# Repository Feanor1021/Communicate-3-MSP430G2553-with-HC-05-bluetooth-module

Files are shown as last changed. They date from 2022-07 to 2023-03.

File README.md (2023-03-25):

# Communicate-3-MSP430G2553-with-HC-05-bluetooth-module

This is a project for communicating between three MSP430G2553 microcontrollers using the HC-05 Bluetooth module. 

## Project Overview

The project consists of three MSP430G2553 microcontrollers connected to HC-05 Bluetooth modules. One microcontroller is designated as the master, and the other two are slaves. The master microcontroller sends commands to the slaves, and the slaves respond with their status. The status of each slave is indicated by an LED on the corresponding microcontroller.

## Usage

### Hardware Setup

The following hardware is required for this project:

- Three MSP430G2553 microcontrollers
- Three HC-05 Bluetooth modules
- Look to altium file for other components (LED, Res, Cap, etc)

The hardware should be set up as shown in the altium file

### Software Setup

To set up the software for this project, you will need to install IAR Studio (Or CCS) and the MSP430G2553 driver. 
Once IAR Studio is installed, open the project in IAR Studio and build the code for each microcontroller. 
You need to change the code for your hc-05 devices. Master device should know the slave device's MAC adresses.

### Usage

Once the hardware and software are set up, turn on the microcontrollers and they will pair them with the master HC-05 automaticaly. 
The slave microcontrollers will respond with their status. If the LED is on, the status will be `on`. If the LED is off, the status will be `off`. Other leds will
be on or off respect to the sensors status.

    FOR DETAILED INFORMATION READ THE RAPOR.

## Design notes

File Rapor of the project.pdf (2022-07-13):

MSP430 9TH PROJECT REFERENCE DOCUMENT

pg. 1

### KOCAELİ UNIVERSITY ENGINEERING FACULTY

# DATA TRANSFER

# BETWEEN 3

# MSP430G2553 VİA

# BLUETOOTH MODULE

HC-05

FURKAN YARDIMCI
210207089
2021-2022

### DEPARTMENT: Electronic and Communacition Engineering

TEACHER: Dr.Öğr.Üyesi AYHAN KÜÇÜKMANİSA (https://avesis.kocaeli.edu.tr/ayhan.kucukmanisa/)

### KOCAELİ, 2021

TABLE OF CONTENTS

ABSTRACT |
BACKGROUND |
•MSP430G2553 |
•HC-05 And Main Logic Of The Embeded System |
What Is AT Commands |
AT commands that we use in our project |
Main Logic |
- FLAME SENSOR |
•MQ-4 GAS SENSOR |
SYSTEM DESİGN |
•SCHEMATİC AND PCB |
•CODES |
CODES OF SLAVES |
CODE OF MASTER |
IMAGES OF THE SYSTEM IN OPERATING MODE |
REFERENCES |

### 1.ABSTRACT:

An embedded system application that communicates 3 msp430g2553 via bluetooth modules. Using the Bluetooth module (hc-05), 2 slave and 1 master configurations are set between the msps. As a result of analog data coming from the slaves, which came from Fire sensor and MQ-4 gas sensor, the led indicators connected to the master light up.

### 2.BACKGROUND:

### 2.1 MSP430G2553:

Texas Instruments MSP430G2553 is part of the MSP430 family of ultra-low-power microcontrollers featuring different sets of peripherals. The MSP430G2553 mixed signal microcontroller features a 16-bit Semi RISC CPU, 16-bit registers, 16KB non-volatile memory, 512 bytes RAM. The G2x53 series is popular due to the low price and various package sizes. We have use 3 msp430g2553 in our project, 2 of them act as slaves and one is master.

### 2.2 HC-05 And Main Logic Of The Embeded System:

HC-05 Bluetooth Module is an easy to use Bluetooth SPP (Serial Port Protocol) module, designed for transparent wireless serial connection setup. Its communication is via serial communication which makes an easy way to interface with controller or PC. HC-05 Bluetooth module provides switching mode between master and slave mode which means it able to use neither receiving nor transmitting data. Master, slave modes and lots of modes are, arrenged with AT command of the hc-05, wich is so important for our project

a)What Is AT Commands ?

By default, the HC-05 is configured in data mode. In this mode, the module acts like a serial bridge. If you want to set an HC-05 as a master you have to put it into AT command mode. To put into AT command mode the KEY pin must be set (high). The HC-05 is now in command mode if the red LED flashes once every two seconds.

b)AT commands that we use in our project:

Set/Inquire module role:
AT+ROLE=PARAM1 → Role introduction: Slave: Passive connection; Slave-Loop: Passive connection, receive the remote Bluetooth master device data and send it back to the master device; Master: Inquire the near SPP Bluetooth slave device, build connection with it positively, and build up the transparent data transmission between master and slave device. Default: 0

Param1: module role: 0 -> Slave
1 -> Master
2 -> Slave-Loop

Set/Inquire connection mode:
AT+CMODE=Param1→ Param1: Connection mode: 0 -> Connect the module to the specified Bluetooth address. (Bluetooth address can be specified by the binding command)
1 -> Connect the module to any address (The specifying address has no effect for this mode.) 2 -> Slave-Loop
Default connection mode: 0

Set/Inquire - bind Bluetooth address:
AT+BIND=Param1 → Param1: Bluetooth address: needed to be bind

Connect Device :
AT+LINK=Param1 → Param1: Bluetooth address of remote device

AT commands of master hc-05 is:

AT+ROLE=1 AT+CMODE=0

AT commands of slaves is:

AT+ROLE=0 AT+CMODE=1;

c)Main Logic:

In our project we have 2 slaves and 1 master but hc-05 is support just one slave connection to the master at a time. As a solution to this, the master was cycled between continuous in AT mode and data mode, and we achived this with switching the reset pin(11th pin) of Hc-05 with BC238 switch circuit. First master hc-05 is goes into the at mode, then the address of the 1st slave is bind to master, then it has reset and goes into data mode, and it is communicate with slave 1. With this loopish approach, we have able to control 2 slaves with a single master.

### 2.3 Flame Sensor:

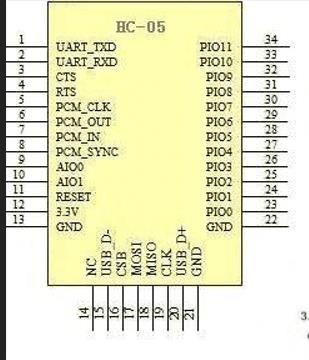
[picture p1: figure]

The fire detector sensor card is a sensor card used to detect fire with a wavelength between 760 nm -1100 nm. It has an IR receiver on it. It can be used as a fire detection sensor in fire extinguishing robots. Sensitivity can be adjusted with the trimpot on it and both analog and digital output can be output.

### 2.4 MQ-4 Gas Sensor:

The MQ-4 methane gas sensor detects the presence of methane (CNG) natural gas in a range of concentrations suitable for gas leak detection between 300ppm and 10000ppm. Like other MQ sensors, this sensor also gives an analog voltage output according to the density of the gas. Being able to detect between 10.000ppm and 300ppm is suitable for gas leakage.

### 3. System Design

### 3.1 Schematic and PCB:

This system’s schematic was designed using Altium Designer 17.0 and can be seen in the Figure below...

a)MASTER Circuit:

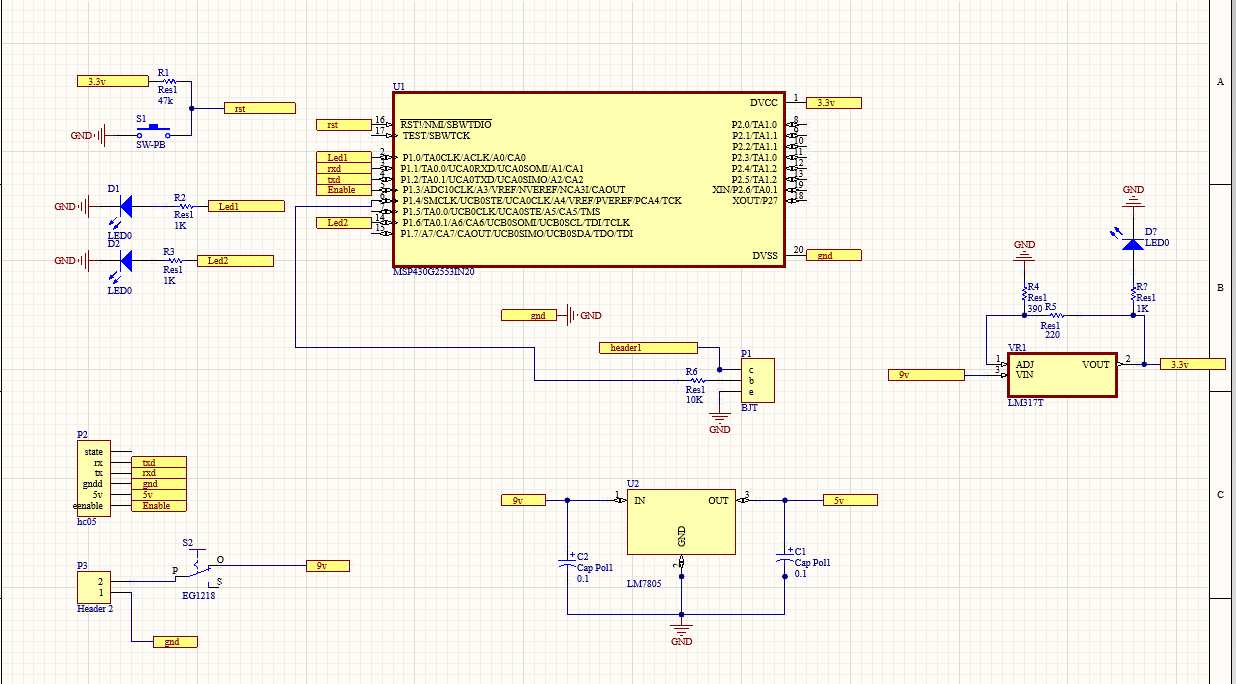
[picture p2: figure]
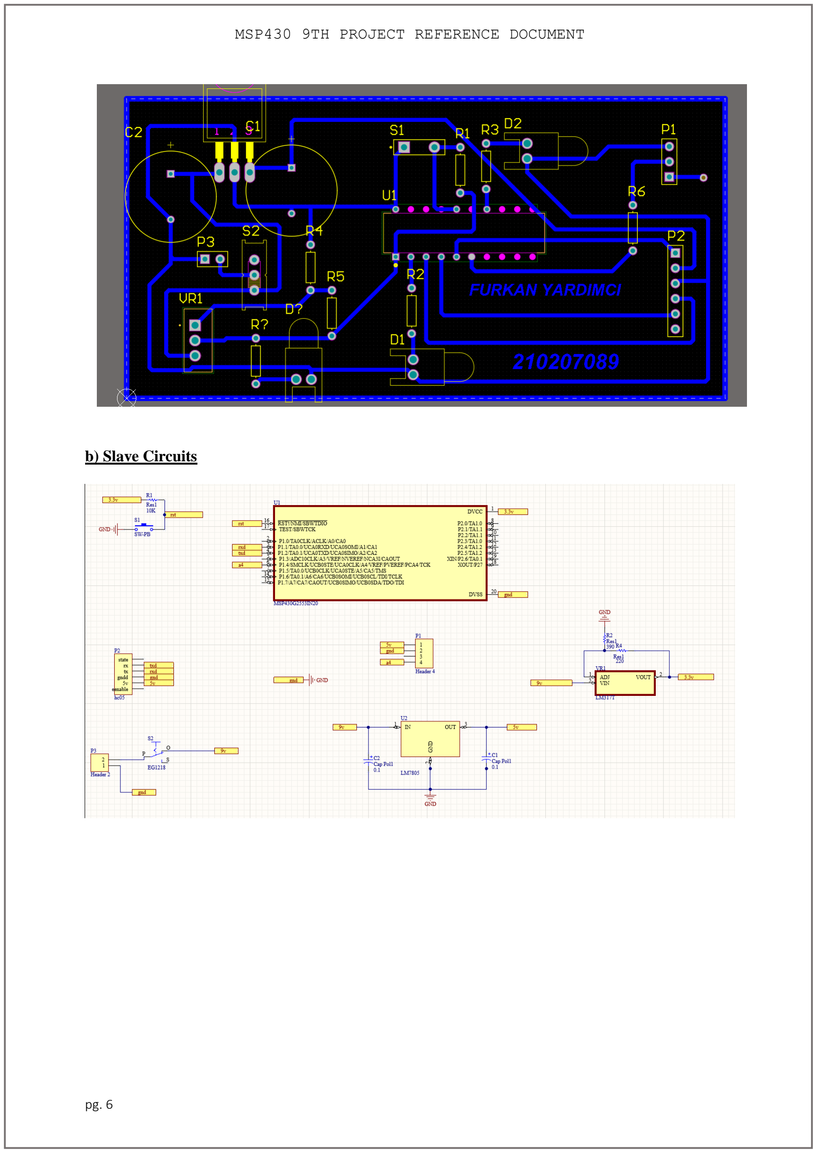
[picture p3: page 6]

b) Slave Circuits

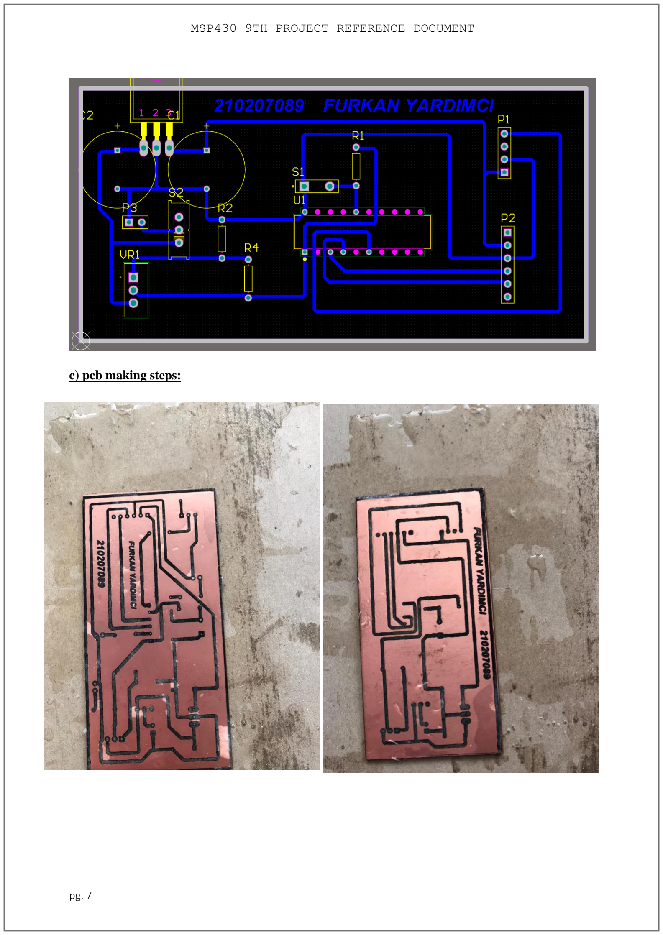
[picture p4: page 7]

c) pcb making steps:

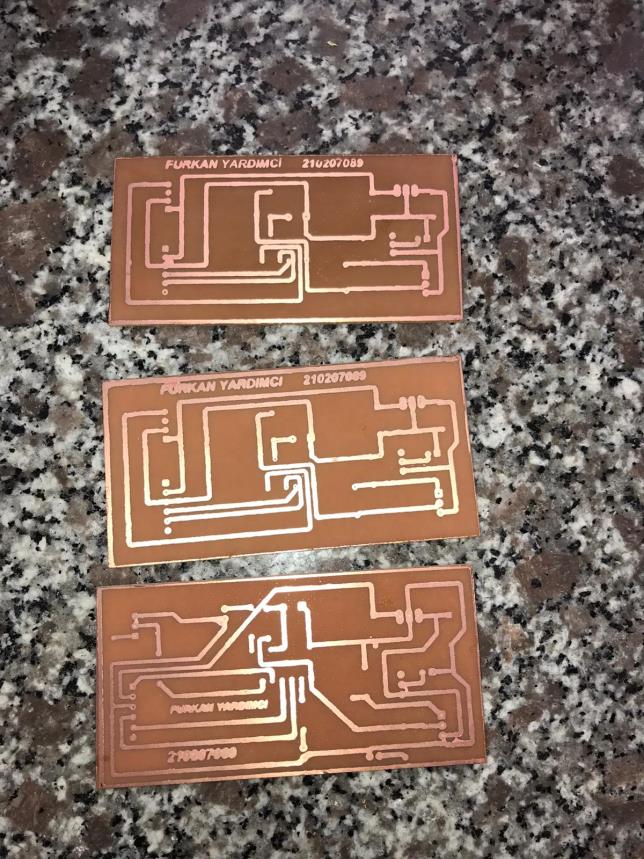
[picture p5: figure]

### 3.2 Codes:

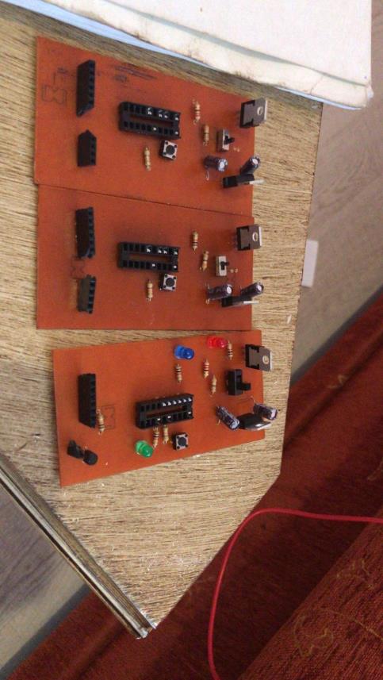
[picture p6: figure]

This project code was written in c language and separate codes were written for master and slaves.

a.1) CODES OF SLAVES: slave codes are almost exactly the same so I'm just putting one of them in the report

ADC Register Initializations

Register | Bit | Description
ADC10CTL0 | REFON | Reference generator: ON
ADC10CTL0 | SREF_1 | Select reference voltage as 1.5v
ADC10CTL0 | ADC10ON | ADC10 Enable: ON
ADC10CTL0 | ADC10IE | ADC10 Interrupt: ENABLED
ADC10CTL0 | ADC10SHT_3 | Sample and holde time: 64xAdc10clk
ADC10CTL0 | ENC | Enable conversion
ADC10CTL0 | ADC10SC | Start Conversion
ADC10CTL1 | INCH_4 | Input channel A4 (P1.4)
ADC10CTL1 | ADC10SSEL_0 | ADC10OSC selected as a clk source

ADC10CTL1 | ADC10DIV_3 | ADC10OSC clk divided by 2
ADC10AE | BIT4 | Analog input enable bit is set for Port 1.4

UART Register Initializations

Register | Bit | Description
P1SEL | BIT1 + BIT2 | P1.1 = RXD, P1.2=TXD
P1SEL2 | BIT1 + BIT2 | P1.1 = RXD, P1.2=TXD
UCA0CTL1 | UCSSEL_2 | Set UART use SMCLK
UCA0BR0 | 104 | 1MHz 9600 baud
UCA0BR1 | 0 | 1MHz 9600 baud
UCA0MCTL | UCBRS_1 | Modulation UCBRSx = 1
IE2 | UCA0RXIE | Rx interrupts are enabled
UCA0CTL1 | ~UCSWRST | Resets are disabled

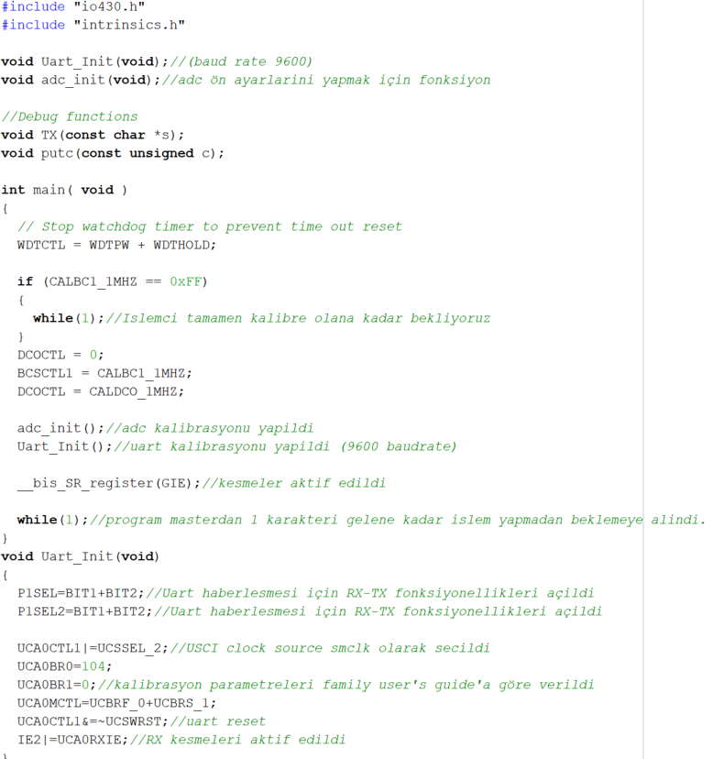
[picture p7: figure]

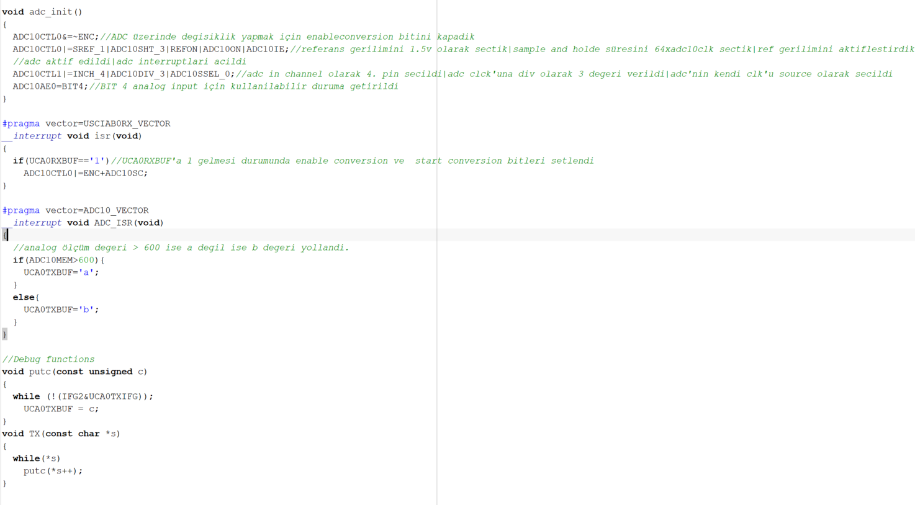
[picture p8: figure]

a.2) Functions:

Function | Description
void TX(const char *s) | Send a string via UART
void putc(const unsigned c) | Send a character via UART
void Uart_Init(void); | Initilazation of Uart communication
void adc_init(void); | Initilazation of ADC10
b) Code Of Master:

UART Register Initializations for 9600 baud rate. This baud rate used for BT to BT communication.

Register | Bit | Description
P1SEL | BIT1 + BIT2 | P1.1 = RXD, P1.2=TXD
P1SEL2 | BIT1 + BIT2 | P1.1 = RXD, P1.2=TXD
UCA0CTL1 | UCSSEL_2 | Set UART use SMCLK
UCA0BR0 | 104 | 1MHz 9600 baud
UCA0BR1 | 0 | 1MHz 9600 baud
UCA0MCTL | UCBRS_1 | Modulation UCBRSx = 1
IE2 | UCA0RXIE | Rx interrupts are enabled
UCA0CTL1 | ~UCSWRST | Resets are disabled

UART Register Initializations for 38400 baud rate. This baud rate used for sending AT command to the module

Register | Bit | Description
P1SEL | BIT1 + BIT2 | P1.1 = RXD, P1.2=TXD
P1SEL2 | BIT1 + BIT2 | P1.1 = RXD, P1.2=TXD
UCA0CTL1 | UCSSEL_2 | Set UART use SMCLK
UCA0BR0 | 26 | 1MHz 9600 baud
UCA0BR1 | 0 | 1MHz 9600 baud
UCA0MCTL | UCBRS_0 | Modulation UCBRSx = 0
IE2 | UCA0RXIE | Rx interrupts are enabled
UCA0CTL1 | ~UCSWRST | Resets are disabled

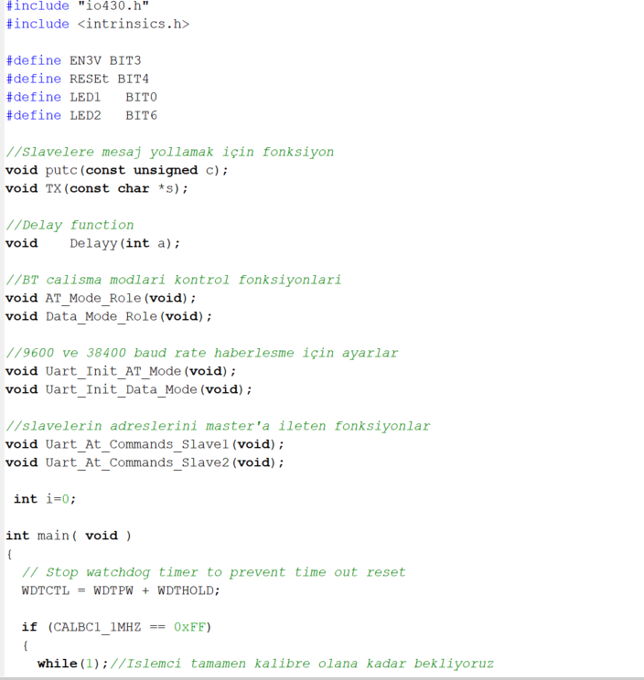
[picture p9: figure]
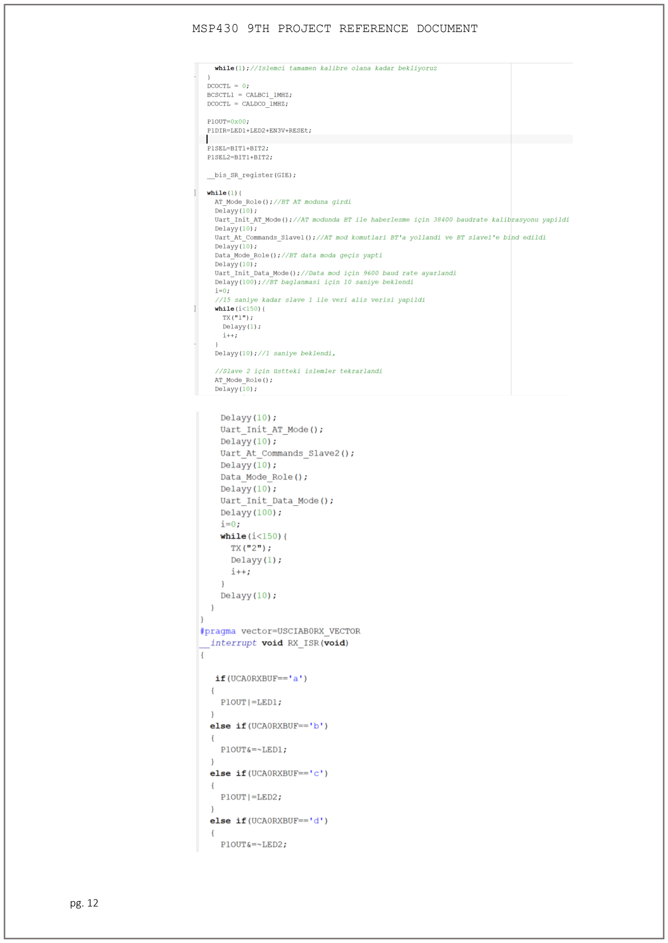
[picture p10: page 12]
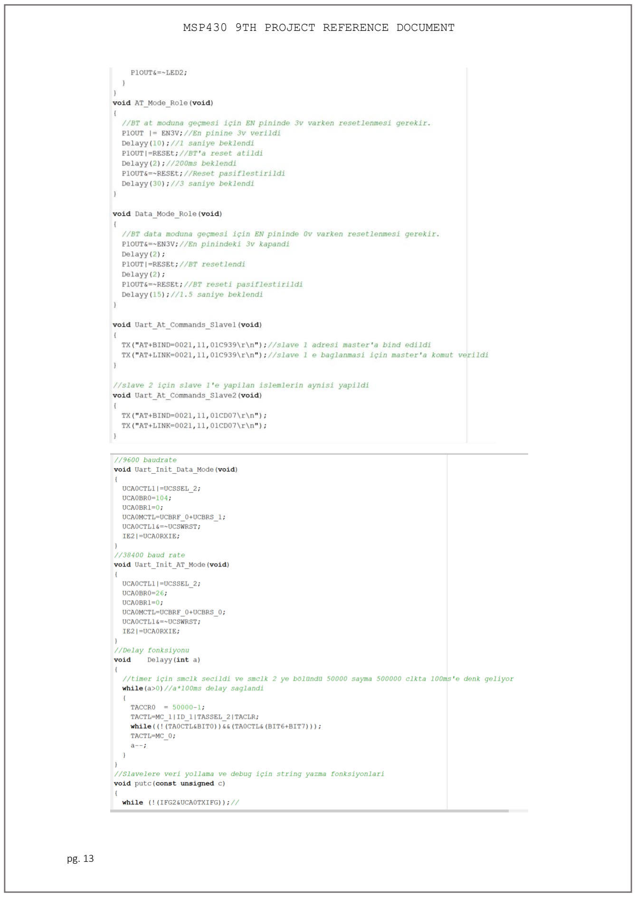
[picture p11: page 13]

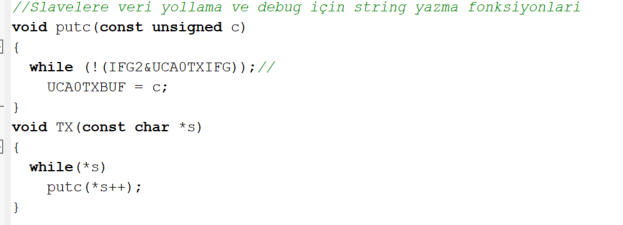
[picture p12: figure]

b.2) Functions:

Function | Description
void TX(const char *s) | Send a string via UART
void putc(const unsigned c) | Send a character via UART
void Uart_Init(void); | Initilazation of Uart communication
void adc_init(void); | Initilazation of ADC10
void Delayy(int a); | A function that produces a delay of a*100ms
void AT_Mode_Role(void); | Function that makes the necessary bias setting for Bluetooth to switch to at mode
void Data_Mode_Role(void); | Function that makes the necessary bias setting for Bluetooth to switch to data mode
void Uart_Init_AT_Mode(void); | Function that initialize uart setting for at mode of the Bluetooth module.(38400 baud rate)
void Uart_Init_Data_Mode(void); | Function that initialize uart setting for data mode of the Bluetooth module.(9600 baud rate)
Void Uart_At_Commands_Slave1(void); | Function that bind and connect master to slave 1
void Uart_At_Commands_Slave2(void); | Function that bind and connect master to slave 2

### 4. Images Of The System In Operation:

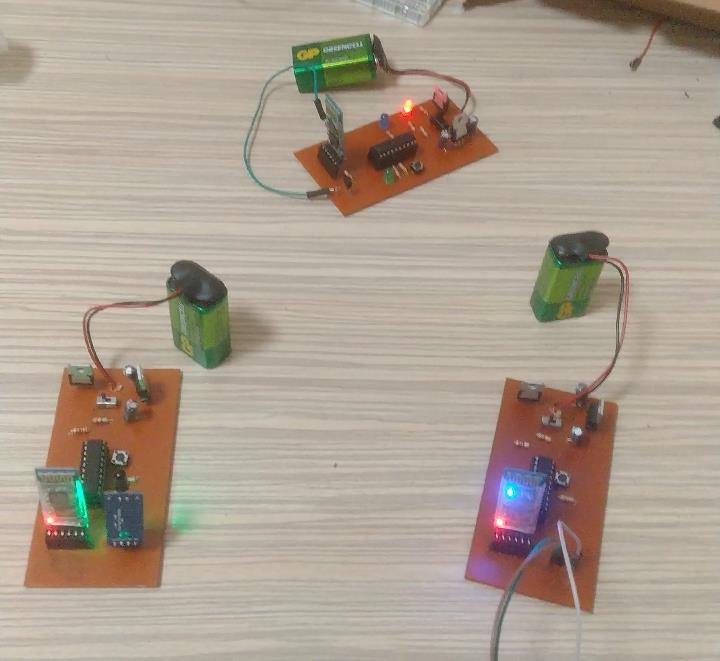
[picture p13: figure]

5.REFERENCES:

https://www.ti.com/lit/ug/slau772a/slau772a.pdf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 (https://www.ti.com/lit/ug/slau772a/slau772a.pdf?ts=1648994984108)

https://www.ti.com/lit/ug/slau144j/slau144j.pdf

https://www.saibatudomt.com.br/2018/01/conectando-3-dispositivos-arduino-utilizando-o-modulo-bluetooth-hc-05/ (https://www.saibatudomt.com.br/2018/01/conectando-3-dispositivos-arduino-utilizando-o-modulo-bluetooth-hc-05/)

https://forum.arduino.cc/t/hc05-bluetooth-with-multi-slaves/274151

https://forum.arduino.cc/t/hc-05-master-and-slave-at-the-same-time/535604

https://wiki.analog.com/university/courses/eps/bjt-switch

https://www.electronicwings.com/ti-launchpad/hc-05-bluetooth-module-interfacing-with-msp-exp430g2-ti-launchpad (https://www.electronicwings.com/ti-launchpad/hc-05-bluetooth-module-interfacing-with-msp-exp430g2-ti-launchpad)

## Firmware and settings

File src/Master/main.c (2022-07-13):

#include "io430.h"
#include <intrinsics.h>

#define EN3V BIT3 //EN pin of the BT
#define RESEt BIT4 //11. pin of the BT whic is used for reset BT
#define LED1   BIT0 //indicator led1
#define LED2   BIT6 //indicator led2

//you should write your slave adresses here.
#define SLAVE1BIND "AT+BIND=0021,11,01C939\r\n"
#define SLAVE2BIND "AT+BIND=0021,11,01CD07\r\n"
#define SLAVE1LINK "AT+LINK=0021,11,01C939\r\n"
#define SLAVE2LINK "AT+LINK=0021,11,01CD07\r\n"

//Functions for sending string to slaves
void putc(const unsigned c);
void TX(const char *s);

//Delay function 0.1ms * a. ex a = 5 == 0.5 = 500ms delay.
void    Delayy(int a); // you can switch all of the delays of the program. The delays are experimental lesser delays are may work proper too.

//BT Mode control functions.
void AT_Mode_Role(void); // AT mode
void Data_Mode_Role(void); // Data mode

//9600 ve 38400 baud rate init funcs.
void Uart_Init_AT_Mode(void); // 38400 br
void Uart_Init_Data_Mode(void); // 9600 br

//functions for binding the master to slaves
void Uart_At_Commands_Slave1(void);
void Uart_At_Commands_Slave2(void);

int i=0; //simple counter var.
 
int main( void )
{
  // Stop watchdog timer to prevent time out reset
  WDTCTL = WDTPW + WDTHOLD;
  
  if (CALBC1_1MHZ == 0xFF)
  {
    while(1);//Wait till proccessor fully calibrated.
  }
  DCOCTL = 0;
  BCSCTL1 = CALBC1_1MHZ;
  DCOCTL = CALDCO_1MHZ;
  
  P1OUT=0x00; //init of outputs
  P1DIR=LED1+LED2+EN3V+RESEt;
  
  P1SEL=BIT1+BIT2;//TX RX inits
  P1SEL2=BIT1+BIT2;//TX RX inits
  
  __bis_SR_register(GIE); //General interrupt enable
  
  while(1){
    AT_Mode_Role();//BT went into AT mode.
    Delayy(10);
    Uart_Init_AT_Mode();//38400 baudrate for uart is set which is required for AT commands.
    Delayy(10);
    Uart_At_Commands_Slave1();//Master connected to slave 1
    Delayy(10);
    Data_Mode_Role();//BT went into DATA mode
    Delayy(10);
    Uart_Init_Data_Mode();//9600 baudrate for uart is set which is required for DATA commands.
    Delayy(100);//Wait for bt connection
    i=0;
    //Connection established with slave 1 for 15 seconds
    while(i<150){
      TX("1");
      Delayy(1);
      i++;
    }
    Delayy(10);
    
    //Same process for slave 2
    AT_Mode_Role();
    Delayy(10);
    Uart_Init_AT_Mode();
    Delayy(10);
    Uart_At_Commands_Slave2();
    Delayy(10);
    Data_Mode_Role();
    Delayy(10);
    Uart_Init_Data_Mode();
    Delayy(100);
    i=0;
    while(i<150){
      TX("2");
      Delayy(1);
      i++;
    }
    Delayy(10);
  }
}

//interrupt for UCA0RXBUF control.
#pragma vector=USCIAB0RX_VECTOR
__interrupt void RX_ISR(void)
{
   if(UCA0RXBUF=='a')
  {
    P1OUT|=LED1;
  }
  else if(UCA0RXBUF=='b')
  {
    P1OUT&=~LED1;
  }
  else if(UCA0RXBUF=='c')
  {
    P1OUT|=LED2;
  }
  else if(UCA0RXBUF=='d')
  {
    P1OUT&=~LED2;
  }
}
void AT_Mode_Role(void)
{
  //It must be reset with 3v on the EN pin for it to switch to BT at mode.
  P1OUT |= EN3V;//3V is set
  Delayy(10);//wait 1 sec
  P1OUT|=RESEt;//Reset bluetooth
  Delayy(2);//wait 0.2 sec 
  P1OUT&=~RESEt;//close the reset
  Delayy(30);//wait 3 sec
}

void Data_Mode_Role(void)
{
  //To switch to BT data mode, it must be reset when there is 0v on the EN pin.
  P1OUT&=~EN3V;//3V is closed
  Delayy(2);
  P1OUT|=RESEt;//BT is reseted
  Delayy(2);
  P1OUT&=~RESEt;//reset is closed
  Delayy(15);// wait 1.5 sec
}

//Bind and link commands
void Uart_At_Commands_Slave1(void)
{
  TX(SLAVE1BIND);
  TX(SLAVE1LINK);
}
void Uart_At_Commands_Slave2(void)
{
  TX(SLAVE2BIND);
  TX(SLAVE2LINK);
}

//9600 baudrate
void Uart_Init_Data_Mode(void)
{ 
  UCA0CTL1|=UCSSEL_2;
  UCA0BR0=104;
  UCA0BR1=0;
  UCA0MCTL=UCBRF_0+UCBRS_1;
  UCA0CTL1&=~UCSWRST;
  IE2|=UCA0RXIE;
}
//38400 baudrate
void Uart_Init_AT_Mode(void)
{ 
  UCA0CTL1|=UCSSEL_2;
  UCA0BR0=26;
  UCA0BR1=0;
  UCA0MCTL=UCBRF_0+UCBRS_0;
  UCA0CTL1&=~UCSWRST;
  IE2|=UCA0RXIE;
}
//Delay function
void    Delayy(int a)
{
  while(a>0)// a * 0.1 sec delay
  {
    TACCR0  = 50000-1;
    TACTL=MC_1|ID_1|TASSEL_2|TACLR;
    while((!(TA0CTL&BIT0))&&(TA0CTL&(BIT6+BIT7)));
    TACTL=MC_0;
    a--;
  }
}
// String writing functions for sending data to slaves and debugging
void putc(const unsigned c)
{
  while (!(IFG2&UCA0TXIFG));//Wait till tx is free
    UCA0TXBUF = c;
}
void TX(const char *s)
{
  while(*s)
    putc(*s++);
}

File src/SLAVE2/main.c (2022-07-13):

#include "io430.h"
#include "intrinsics.h"

void Uart_Init(void);//9600 baud rate
void adc_init(void);//init. of the adc10

//Debug functions
void TX(const char *s);
void putc(const unsigned c);

int main( void )
{
  // Stop watchdog timer to prevent time out reset
  WDTCTL = WDTPW + WDTHOLD;
  
  if (CALBC1_1MHZ == 0xFF)
  {
    while(1);//wait till the processor is fully calibrated
  }
  DCOCTL = 0;
  BCSCTL1 = CALBC1_1MHZ;
  DCOCTL = CALDCO_1MHZ;
  
  adc_init();//calibration of the adc10 is done
  Uart_Init();//calibration of the uart module is done
  
  __bis_SR_register(GIE+LPM4_bits);//general interrupt enable and lmp4 bits are set
  
  while(1);//BT will sleep till '1' is reached its RX channel.
}
void Uart_Init(void)
{  
  P1SEL=BIT1+BIT2;//RX-TX
  P1SEL2=BIT1+BIT2;//RX-TX
  
  UCA0CTL1|=UCSSEL_2;//SMCLK
  UCA0BR0=104;
  UCA0BR1=0;
  UCA0MCTL=UCBRF_0+UCBRS_1;
  UCA0CTL1&=~UCSWRST;
  IE2|=UCA0RXIE;//RX interrupts is set
}

void adc_init()
{
  ADC10CTL0&=~ENC;// Disable Conversation - ADC10CTL0 REGISTER CANNOT BE MODYFIED WHILE EMC IS ENABLED. 
  ADC10CTL0|=SREF_1|ADC10SHT_3|REFON|ADC10ON|ADC10IE;// necessary settings have been made
  ADC10CTL1|=INCH_4|ADC10DIV_3|ADC10SSEL_0;
  ADC10AE0=BIT4;// BIT is made available for 4 analog inputs
}

#pragma vector=USCIAB0RX_VECTOR
__interrupt void isr(void)
{
  if(UCA0RXBUF=='2')//if it recives '1' on its RX channel then start the ADC10
    ADC10CTL0|=ENC+ADC10SC;
}

#pragma vector=ADC10_VECTOR
__interrupt void ADC_ISR(void)
{
  //if analog value is over 600 then send a to master else send b
  if(ADC10MEM>600){
    UCA0TXBUF='d';
  }
  else{
    UCA0TXBUF='c';
  }
}
 
//Debug functions
void putc(const unsigned c)
{
  while (!(IFG2&UCA0TXIFG));
    UCA0TXBUF = c;
}
void TX(const char *s)
{
  while(*s)
    putc(*s++);
}
